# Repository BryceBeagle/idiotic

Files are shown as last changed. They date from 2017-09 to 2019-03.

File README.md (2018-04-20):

The purpose of this project was to create a modular Internet of Things (IoT) system to create an interface between DIY
devices and consumer grade products. The end product is focused on the automation of household tasks and behaviors for
these devices, with functionality resembling a combination of IFTTT (If This Then That; used for integration between
different web services) and Tasker (used for automating system actions on a cellphone). Users have the ability to
integrate devices and services from off-the-shelf products and services, as well as third party or homebrewed solutions.

This project provides a design architecture as well as an implementation thereof. The architecture describes a system
that addresses all of the design requirements, while the implementation makes it happen. The implementation provides the
software required to run the system, as well as a set of physical modules that are able to work with it. The modules
include parts lists, PCB schematics, board designs, and embedded software ‒ everything required to create and deploy one
from scratch.

Users are able to configure their system to create collections of tasks, called routines, that are triggered by internal
or external state changes, such as the time transitioning to a predesignated time of the day, or a door being opened.
These routines contain events, or sequences of actions to perform, where each action is an atomic operation for a device
to execute. A routine can contain one or more events, and each event can contain one or more actions to perform. For
example, if a user wants their Philips Hue internet-connected light bulbs to turn on automatically when they open a
specific door, they can create a routine that is run when a predesignated door sensor is activated. Devices send status
updates to a server which listens to the changing values and notifies routines that are subscribed to pieces of data.

The system has a server that handles connections and routes incoming data to device driver instances using a data
control library, henceforth referred to as the controller. The controller manages routines and events in the system as
well as the data structure that holds all of the device instances. Devices, both physical (e.g., a Temperature Sensor)
and cloud-based (e.g., a Google Home), are configured for use by the controller with driver files that express the
capabilities of the hardware or software that they represent. For example, a driver for the Philips Hue smart light
bulbs would express the ability to set and retrieve attributes such as brightness, hue, saturation and on/off state, as
well as behaviors such as dimming and pulsing.

Routines, events, and devices are stored in a configuration, allowing the system to start up preconfigured and ready for
use. Events referenced in routines must have corresponding configuration entries describing them, and devices mentioned
in events must also have drivers that the controller can access and utilize. Storing configurations in non-volatile,
text-based formats allows them to be version controlled, shared, and edited with relative ease.

The software provided with this project, called Idiotic, is an extendable implementation of the system described above.
It is written in Python 3, with the server implemented with the Flask web framework library. Routines, events, and
devices are loaded from JSON configuration files. There are also a small number of PCB devices, designed using Eagle,
that function with the system as a demonstration of functionality.

Developers that wish to integrate their own devices into Idiotic can make use of the server’s client platform agnostic
websocket-based API to integrate their device within the system, using the simple, documented protocol. Creating a
single driver file in a designated directory is all that is required to allow the controller to handle data from, and
make commands to, a new device type. All integrated devices are treated as a first-class citizens within the system.

Furthermore, if the new device is built on an ESP8266 microcontroller platform, there is a provided library that allows
for expedited embedded development and integration within the system. A developer simply needs to extend a template file
to map which functions are correlated with which pieces of data and behaviors. If the new device is unable to utilize
this library, it simply needs to connect to the server over a Websocket and follow a simple communication protocol.

Modules currently in the system:
* Door Open/Close Sensor (already developed but revising is necessary)
* IR blaster/receiver **(hardware only)** - Send IR signals to TV (with ability to record and reproduce remote signals)
* HVAC Thermostat
* Temperature sensor
* Hue Light support
		
Core features of the software  include:
* Ability to utilize and integrate all created PCB modules
* Ability to interface modules together to create useful routines and actions
* Ability to add DIY modules with an easy to use interface

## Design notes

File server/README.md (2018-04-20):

# Introduction

`idiotic_server.py` is the entry point of the software portion of this project. It operates as the glue that holds the
Model and Controller together. In the future the server will serve the View of the system. The server operates as the
communication layer between the devices and the controller. Modules send HTTP PUT requests to the server to notify it of
any changes in the information they measure. Modules also occasionally send the values to the server even if they have
not changes as a way of informing the server that the information is still correct.

It is run without arguments using Python 3 and has the following dependencies:

Required:
* `flask` -- Runs the webserver

Optional:
* `phue` -- Required to use Phillips Hue lights and bridges*

<sub><sup>\* currently required because of some hardcoding -- to be optional in future.<sup><sub>

The devices and the server communicate with each other using websockets. The data is sent on the socket in the form of
string encoded JSON structures. Each JSON structure is an object with one or more of two currently supported keys:
hello and update. The value associated with the key is an array of tasks of that type for the recipient to perform.
Depending on the intended recipient of the message, these instructions are slightly different.

An IdioticDevice sends a hello message attempting to establish connection to the server, usually during its
initialization sequence. If the message is a hello message, the json structure must contain a class type in the
"class" key to be associated with the uuid.

Below are example JSON objects, for each message type:

hello structure:
```javascript
{
  "hello": null,
  "uuid": "13:8C:14:87:B7:AD",
  "class": "DoorSensor"
}
```
update structure:
```javascript
{
  "uuid": "13:8C:14:87:B7:AD",
  "update": {
    "door_state": 1,
    "some_value": "some string"
  }
}
```
get structure:
```
[unimplemented]
```

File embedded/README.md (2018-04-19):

# Introduction
Each module is built on top of the ESP8266 embedded platform. All devices connect to a local network and communicate with the `idiotic-server`. Json is tranferred using HTTP Requests and can be used to instruct a device to perform and action or respond with information. 

To aid in simplicity, familiarity and library support, the [Arduino core](https://github.com/esp8266/Arduino "Arduino core") is used. This allows easy programming in C++ with access to a number of convient libraries such as Serial, Wire (TWI/I2C), and Servo.

The [ESP8266WiFi library](https://github.com/esp8266/Arduino/tree/master/libraries/ESP8266WiFi "ESP8266WiFi library") is used to connect the module to a local WiFi network. It's very easy to setup, requiring a single method call with the SSID and password.

Json data structures are  [ArduinoJson library](https://github.com/bblanchon/ArduinoJson "ArduinoJson library"). It provides an easy method of constructing Json data structures that can be turned into strings and sent. 

# Creating your own
It is recommended to use PlatformIO toolchain for development and deployment of software to the ESP8266.

1. If you are developing a new device, create a new directory under `$idiotic/embedded/src` with the name of your device
2. Create a new `.cpp` source file in that directory and open it for editing
3. Import `idiotic_module.hpp` to acquire the base IdioticModule class and its functionality
4. Create an instance of `IdioticModule`, passing the device type as a string.

    Note: This string must exactly match the class name of the corresponding device driver
5. In the setup() function:
    1. Connect the module to WiFi using `IdioticModule::connectWiFi()`
    2. Begin the connection to the Idiotic server using `IdioticModule::beginSocket()`
    3. Populate the `Idiotic::funcs` map with attribute set and get functions using `IdioticModule::function_map`
    structs. The key for each item in the map is the attribute name.

        Note:
        * Each key must have an exact match in the corresponding device driver as either an attribute or a behavior
        * The `.get` function supports lambda expressions, but for an unknown technical reason, I was unable to get this
        working for the `.set` function. As a result, only function pointers are accepted. If a class method is required,
        use `std::bind` for now.
    4. If serial debug output is desired, use `Serial.setDebugOutput(true)`
6. In the loop() function:
    1. Run the dataloop using `IdioticModule::dataLoop()`
    2. Delay the thread to for an amount of time to meet a desired period using `delay()`

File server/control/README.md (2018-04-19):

This directory is for all things controller. A summary of the purposes of each file/directory is provided below:

* `device_drivers/` - Directory where device-drivers should be placed. These files outline the abilities of each device
in the system
* `idiotic_conditional.py` - Contains the `IdioticConditional` class, used by IdioticRoutines and IdioticEvents for
requirements testing before executing
* `idiotic_controller.py` - The meat of the directory. Manages device driver instances and IdioticRoutines
* `idiotic_device.py` - Has base `IdioticDevice` class for device drivers to inherit from, as well as `Attributes` and
`Behavior` decorators
* `idiotic_routine.py` - Contains the `IdioticRoutine` class, which manage the flow of functionality in the system
* `idiotic_trigger.py` - Contains the `IdioticTrigger` class, used by IdioticRoutines to subscribe to device attributes

See the readme in `device_drivers/` for how to create a new device driver to be added to the system

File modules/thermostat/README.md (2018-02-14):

# Introduction
Module that acts as a replacement/attachment to a household thermostat

# Background
A standard thermostat attaches to a number of wires that lead to the HVAC system. These wires typically run at ~24 VAC and are usually color coded. The ones we need to worry about are:

|  Marking | Wire Color  | Purpose  |
| :--- | :--- | :--- |
| R  | Red  | 24 VAC  |
| G  | Green  | Fan Relay  |
| W  | White  | Heat Relay  |
| Y  | Yellow  | AC Relay |

If your current thermostat has a heat anticipator -- [TODO]

# Functionality

# Parts List

# Appendix

**Choosing a current limiting resistor between the ESP and relays**

See [here](https://electronics.stackexchange.com/a/16219/163386 "here") for a great description on how to read the datasheet for a Solid State Relay.

| | |
| - | - |
| ESP Supply Voltage  | 3.3 V  |
| SSR LED Voltage Drop  | 1.2 V  |
| Desired SSR Current | 1 mA |

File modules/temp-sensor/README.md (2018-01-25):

**Description**

Module that measures and reports temperature.

The MCP9808 sensor is functional from -40°C ~ 125°C with an accuracy of ±0.5°C. The ESP8266 communicates with the sensor
using I2C (TWI). Temperature is measured every 30 seconds and a 5 minute rolling average is reported to the server every
30 seconds.

Temperature is reported in °C the following JSON format:
```json
{"temp" : "20.5"}
```

**Parts List**

| Purpose | Component(s) | Purchase Link |
|---|---|---|
| Microcontroller | ESP8266-07 or ESP8266-12E/F/S | [Link](https://www.adafruit.com/product/2491)|
| Temp Sensor | MCP9808 in 8-MPOS package | [Link](https://www.digikey.com/short/q8143w) |
| SMD Female MicroUSB | 609-4613-1-ND | [Link](https://www.digikey.com/short/q81438) |
| 3.3 V Voltage Reg | AZ1117E in SOT-223 package | [Link](https://www.digikey.com/short/q81489) |
| VReg Caps | 2 × 1 μF capacitors in 0805 package | |

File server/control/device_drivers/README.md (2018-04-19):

# Creating a new IdioticDevice

Creating a new IdioticDevice is simple. First, create a new python file in the `control/device_drivers` directory.
Use the following snippet as a template/example for the file:
```python
from control.idiotic_device import IdioticDevice
from control.idiotic_device import Attribute, Behavior

class MyDeviceName(IdioticDevice):

    def __init__(self):
        self._my_attribite = None

    @Attribute
    def my_attribute():
        """Get my_attribute from device or from controller if cached

        Implicit my_attribute.getter
        """
        # In this case, the value is retrieved from cache
        return self._my_attribute

    @my_attribute.setter
    def my_attribute(value):
        """Instruct device to set my_attribute to value"""
        self.ws.get().send(f'{{"set" : {{"{active_device}"}}}}')

    @my_attribute.updater
    def my_attribute(value):
        """Update value of my_attribute in controller's cache"""
        self._my_attribute = value

    @Behavior
    def thing_to_do(param1, param2):
        """Have device do some thing"""
        self.ws.get().send(f'{{"do" : "thing_to_do"}}')

```

IdioticDevices consist of two main components: Attributes and Behaviors. Attributes represent singular values and states,
while Actions are meant to be used to perform something a little more in depth. For example, the brightness of a Hue
Light would be an attribute, and a command used to make the bulb strobe between 3 colors would be an Action.

## Attributes

Attributes represent singular values and states. For example, the brightness of a Hue Light would be an attribute, and
would have a getter and a setter method. Because the HueLights do not ping the server with status information, the
HueLight Attributes would not have updater methods. On the other hand, a temperature sensor whose sole purpose is to
report status would have updater and getter functions for its temp attribute.

Attributes are defined above a function use decorators. The plain @Attribute decorator must be used first and designates
the following function as the getter function for the Attribute. To define a setter or updater function use
`getter_func_name.setter` or `getter_func_name.updater`, where getter_func_name is the name of the function defined as
the getter function.

## Behaviors

Behaviors are abilities that a device can perform, that are slightly more complicated that the setting of a single value
that an attribute setter function provides. An example of a behavior could be a HueLight having a transition ability to
slowly change between two different colors, which would be arguments fort the behavior function. Behaviors are not as
complicated internally as attributes and only have a single method. However, the @Behavior decorator must be used to
tell Idiotic to enumerate the Behavior and allow Routines to call it.

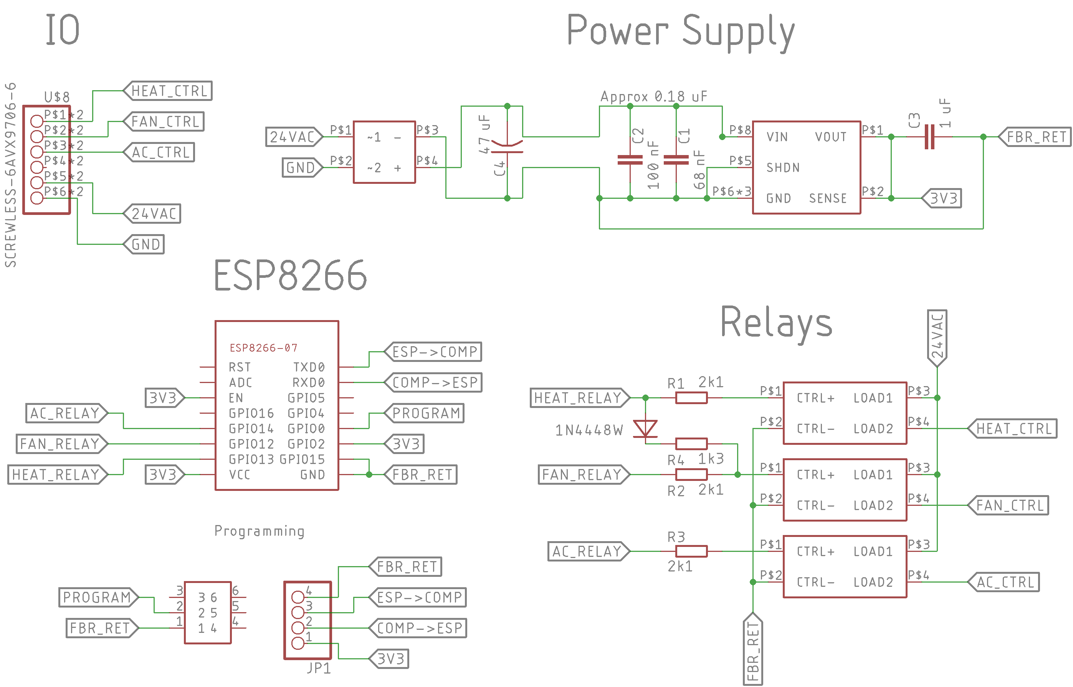
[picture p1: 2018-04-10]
eagle/modules/thermostat/schematic.png

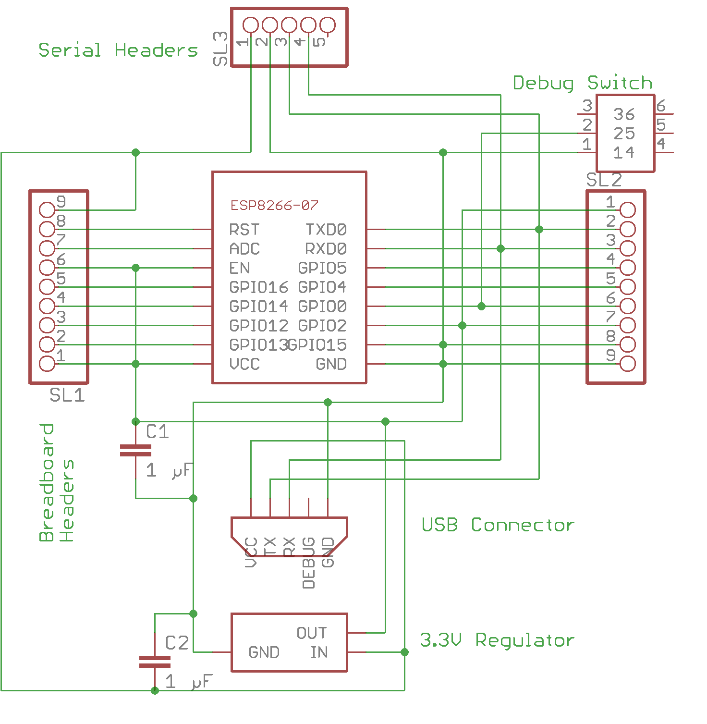
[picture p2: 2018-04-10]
eagle/modules/breakout-board/schematic.png

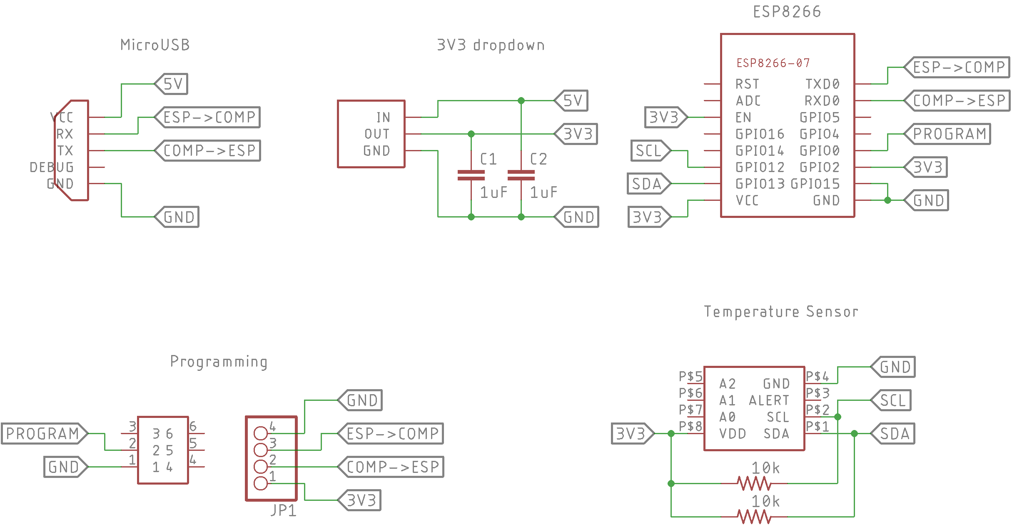
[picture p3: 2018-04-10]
eagle/modules/temp-sensor/schematic.png

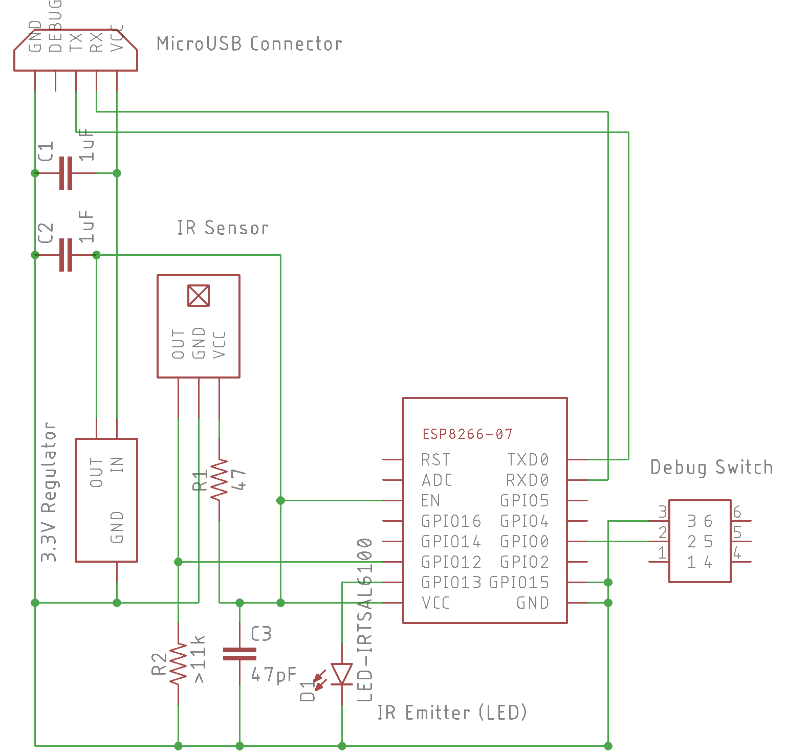
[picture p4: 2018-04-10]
eagle/modules/ir/schematic.png

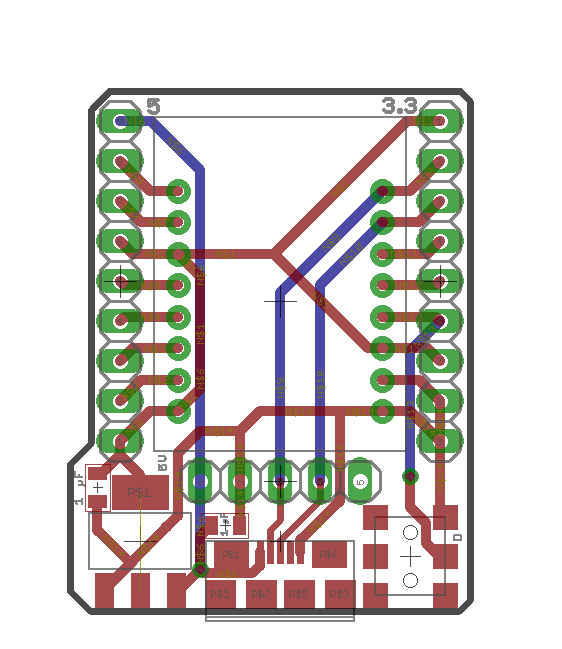
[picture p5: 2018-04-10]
eagle/modules/breakout-board/board.png

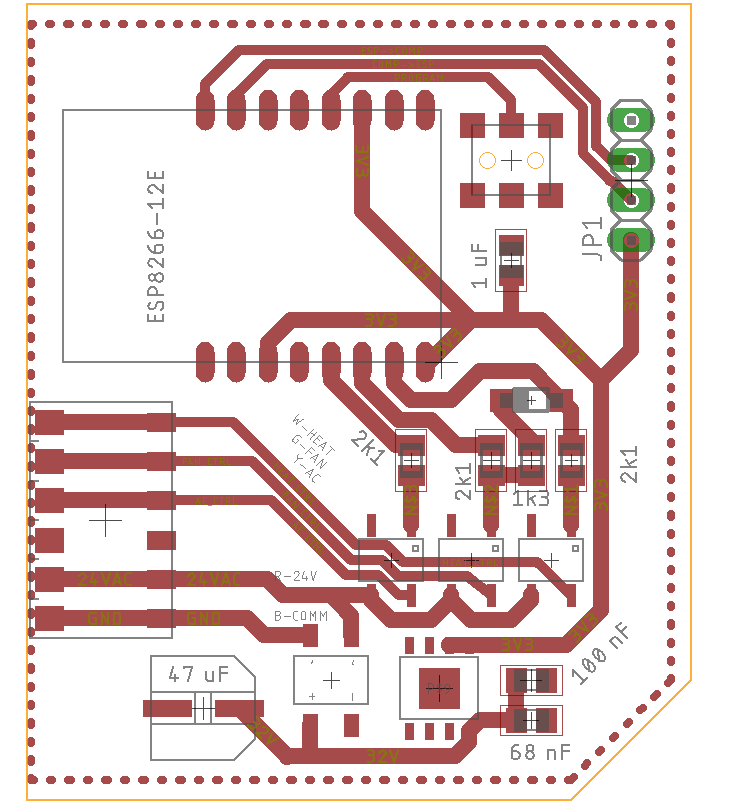
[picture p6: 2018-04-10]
eagle/modules/thermostat/board.png

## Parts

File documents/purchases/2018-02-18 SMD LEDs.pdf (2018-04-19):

701 Brooks Ave South,

### PO Box 677 Thief River Falls, MN 56701-0677

### www.digikey.com Orders 1-800-344-4539 Fax 218-681-3380

## Invoice # 61406250

# Completed Salesorder U.S. $

Claims for pricing errors, shortages, and defective product must be reported within 30 days of invoice date.

## Contact Customer Service at 1-800-858-3616

All transactions with Digi-Key Electronics, including its subsidiaries and/or affiliates, are
subject to Digi-Key's Terms of Use and Conditions of Order, available at www.digikey.com.
DUNS No: 05 760 2120 FEI No: 41-1234968 Any applicable sales tax not collected on this invoice is the responsibility of the customer

### Page: 1 of 2

### Bill To:

### BRYCE BEAGLE 6215 E BEVERLY LN SCOTTSDALE AZ 85254-0000

### Ship To:

### BRYCE BEAGLE BEAGLE ENTERPRISES 6355 S TERRIPIN MESA AZ 85212-0000

### Buyer:

### BRYCE BEAGLE BEAGLE ENTERPRISES 6355 S TERRIPIN MESA AZ 85212-0000

### Ship From:

### DIGI-KEY 701 BROOKS AVE. SOUTH P.O. BOX 677 THIEF RIVER FALLS MN 56701-0677

Salesorder / Packlist: | 53670626 / PL1
Customer: | 9708463
Payment Terms: Shipping Method: Tracking #: | VISA / 2148
| FC
| 9200190106460328886854
Order Source: | INTERNET
Order Date: Invoice Date: Ship Date: | 13-Feb-2018
| 13-Feb-2018
| 13-Feb-2018
Document Date: | 13-Feb-2018/AUTO

### Line

Item | Ordered | Cancelled | Shipped | Item Number/ Description | Unit Price
U.S. $

### Amount

U.S. $

1 | 25 | 0 | 25 | PART: LTST-C191KFKT
CUST: ORANGE SMD LED
| | | | DESC: LED ORANGE CLEAR 0603 SMD LEAD FREE ROHS COMP REACH UNKNOWN
COO : CHINA | ECCN: EAR99 | HTSUS: 8541.40.2000
0.14480 | 3.62 T

Mercury: Cert on File. For more information contact RoHS@DigiKey.com

2 | 25 | 0 | 25 | PART: LTST-C191KSKT CUST: YELLOW SMD LED

DESC: LED YELLOW CLEAR 0603 SMD LEAD FREE ROHS COMP REACH UNKNOWN
COO : CHINA | ECCN: EAR99 | HTSUS: 8541.40.2000
0.16560 | 4.14 T

Mercury: Cert on File. For more information contact RoHS@DigiKey.com

3 | 25 | 0 | 25 | PART: LTST-C191KGKT CUST: GREED SMD LED

DESC: LED GREEN CLEAR 0603 SMD LEAD FREE ROHS COMP REACH UNKNOWN
COO : CHINA | ECCN: EAR99 | HTSUS: 8541.40.2000
0.15560 | 3.89 T

Mercury: Cert on File. For more information contact RoHS@DigiKey.com

4 | 25 | 0 | 25 | PART: LTST-C191KRKT CUST: RED SMD LED

DESC: LED RED CLEAR 0603 SMD LEAD FREE ROHS COMP REACH UNKNOWN
COO : CHINA | ECCN: EAR99 | HTSUS: 8541.40.2000
0.15560 | 3.89 T

Mercury: Cert on File. For more information contact RoHS@DigiKey.com

Total Invoiced
Shipping charges applied
** Charges subtotal **
Sales tax
Total charged to credit card

15.54 -
3.75 -
19.29 -
1.14 -
20.43 -
U.S. $.
T indicates taxable amounts -* These items are controlled by the U.S. Government and authorized for export only to the country of ultimate destination for use by the ultimate consignee or end-user(s) herein identified. They may not be resold, transferred, or otherwise disposed of, to any other country or to any person other than the authorized ultimate consignee or end-user(s), either in their original form or after being incorporated into other items, without first obtaining approval from the U.S. Government or as otherwise authorized by U.S. law and regulations.

Box(es):

701 Brooks Ave South,

### PO Box 677 Thief River Falls, MN 56701-0677

### www.digikey.com Orders 1-800-344-4539 Fax 218-681-3380

## Invoice # 61406250

# Completed Salesorder U.S. $

Claims for pricing errors, shortages, and defective product must be reported within 30 days of invoice date.

## Contact Customer Service at 1-800-858-3616

All transactions with Digi-Key Electronics, including its subsidiaries and/or affiliates, are
subject to Digi-Key's Terms of Use and Conditions of Order, available at www.digikey.com.
DUNS No: 05 760 2120 FEI No: 41-1234968 Any applicable sales tax not collected on this invoice is the responsibility of the customer

### Page: 2 of 2

1 | FC | 9200190106460328886854 | 0.23 kg / 8 oz
25 | LTST-C191KFKT
25 | LTST-C191KSKT
| | | Continued...
25 | LTST-C191KGKT
25 | LTST-C191KRKT

General - WEB ORDER ID: 178395228

CERTIFICATE OF COMPLIANCE:
The Digi-Key components included in the above shipment are genuine components and were provided by the applicable manufacturer to Digi-Key. Test reports (chemical, physical, electrical, etc., together with results of any tests performed by the manufacturer) are on file (either here or in the plant of the manufacturer) and will be made available upon request. These components have been handled in accordance with the requirements of applicable quality standards. This certification is valid only to the original customer and is not transferable. Contact Customer Service at 800-858-3616 if you have any questions.

### Kim Gilbert, Director, Customer Service

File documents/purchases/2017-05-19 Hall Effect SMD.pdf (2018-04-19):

For Office
Use Only
Received | Billing | Pack List No.

## Sold To: Bill To:

Claims for pricing errors, shortages, and defective product must be reported within 30 days of invoice date.

Printing Date

### Back Orders

### Sales Order

### Account

### Customer Purchase Order

Invoice Date | Page
Entered By / Date | Shipped Via

### Terms

Idx | Box | Ordered | Cancelled | Shipped | Item Number/Description | Back Order
Unit Price | Amount
Currency Type: | MSC #

1

1 | 1 | 10 | 0 | 10 AH9246-W-7DICT-ND | .57000 | 5.70 T
| | | | MAGNETIC SWITCH OMNIPOLAR SC59
| | | | CUST REF #: SMD HALL EFFECT
HTSUS: 8542.39.0001 | ECCN: EAR99
LEAD: LEAD FREE | ROHS: ROHS COMP | REACH: REACH | UNAFFECTED | JAN-2017

### Mercury: Cert on File. For more information contact RoHS@DigiKey.com

| | | | COUNTRY/ORIGIN: CHINA
| | | | CAGE: 6M0U4
| | | | PACKAGE TRACKING #: 9200190106460324890602
BOX | 1 SHIPPED FC | WEIGHT | 0 LBS 5 OZS (0.14 KG)
| | | | BOX ID 9200190106460324890602
| | | | TOTAL INVOICED | | 5.70
| | | | SHIPPING CHARGES APPLIED | | 2.85
| | | | ** CHARGES SUBTOTAL ** | | 8.55
| | | | SALES TAX | | .42
| | | | (T INDICATES TAXABLE AMOUNTS)
| | | | TOTAL CHARGED TO CREDIT CARD | | 8.97
| | | | | | U.S. $$

### YOUR CREDIT CARD HAS BEEN CHARGED THE ABOVE INDICATED AMOUNT

| | | | THE ORDER IS COMPLETE
| | | | Ship To: BRYCE BEAGLE
| | | | BEAGLE ENTERPRISES
| | | | 6355 S TERRIPIN
| | | | MESA AZ 85212-0000
| | | | Ship From: DIGI-KEY
| | | | 701 BROOKS AVE. SOUTH
| | | | P.O. BOX 677
| | | | THIEF RIVER FALLS MN 56701-0677
| | | | General - WEB ORDER ID: 168880240

## www.digikey.com Orders 1-800-344-4539 Fax 218-681-3380

# Invoice # 57865523

U.S. $

### 701 Brooks Ave. South, Thief River Falls, MN 56701-0677 USA

### CUSTOMER 9708463 BRYCE BEAGLE BEAGLE ENTERPRISES 6355 S TERRIPIN MESA AZ 85212-0000

Visa | 19-MAY-2017

50520347

Accepts to 14-MAY-2018 | 2897396

## BRYCE BEAGLE 6215 E BEVERLY LN SCOTTSDALE AZ 85254-0000

### Ship Date

AUTO/19-MAY-2017 | FC | 19-MAY-2017

# Easy to Remember: 1-800-DIGI-KEY

VAT/Tax ID
INTERNET | BILL SHIP | 1 | 19-MAY-2017 | U.S. $ | 0
US $ | US $

# Contact Customer Service at 1-800-858-3616

## All transactions with Digi-Key, including its subsidiaries and/or affiliates, are subject to Digi-Key's Terms of Use and

Conditions of Order, available at www.digikey.com.

DUNS No: 05 760 2120 FEI No: 41-1234968 Any applicable sales tax not collected on this invoice is the responsibility of the customer.

## Sold To:

Claims for pricing errors, shortages, and defective product must be reported within 30 days of invoice date.

Idx | Box | Ordered | Cancelled | Shipped | Item Number/Description | Back Order
Unit Price | Amount

Terms

Customer Purchase Order

Invoice Date | Page

Shipped Via

2

## www.digikey.com Orders 1-800-344-4539 Fax 218-681-3380

# Invoice # 57865523

U.S. $

### 701 Brooks Ave. South, Thief River Falls, MN 56701-0677 USA

### CUSTOMER 9708463 BRYCE BEAGLE BEAGLE ENTERPRISES 6355 S TERRIPIN MESA AZ 85212-0000

Visa | 19-MAY-2017

FC

## Easy to Remember: 1-800-DIGI-KEY

US $ | US $

# Contact Customer Service at 1-800-858-3616

## All transactions with Digi-Key, including its subsidiaries and/or affiliates, are subject to Digi-Key's Terms of Use and

Conditions of Order, available at www.digikey.com.

DUNS No: 05 760 2120 FEI No: 41-1234968 Any applicable sales tax not collected on this invoice is the responsibility of the customer. These items are controlled by the U.S. Government and authorized for export only to the country of ultimate destination for use by the ultimate consignee or end-user(s) herein identified. They may not be resold, transferred, or otherwise disposed of, to any other country or to any person other than the authorized ultimate consignee or end-user(s), either in their original form or after being incorporated into other items, without first obtaining approval from the U.S. Government or as otherwise authorized by U.S. law and regulations.

CERTIFICATE OF COMPLIANCE: | The Digi-Key components included in the above shipment are genuine components and were provided by the applicable manufacturer to Digi-Key. Test reports (chemical, physical, electrical, etc., together with results of any tests performed by the manufacturer) are on file (either here or in the plant of the manufacturer) and will be made available upon request. These components have been handled in accordance with the requirements of applicable quality standards. This certification is valid only to the original customer and is not transferable. Contact Customer Service at 800-858-3616 if you have any questions.
| Kim Gilbert, Director, Customer Service

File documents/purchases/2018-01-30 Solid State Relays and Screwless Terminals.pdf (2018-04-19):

For Office
Use Only
Received | Billing | Pack List No.

## Sold To: Bill To:

Claims for pricing errors, shortages, and defective product must be reported within 30 days of invoice date.

Printing Date

### Back Orders

### Sales Order

### Account

### Customer Purchase Order

Invoice Date | Page
Entered By / Date | Shipped Via

### Terms

Idx | Box | Ordered | Cancelled | Shipped | Item Number/Description | Back Order
Unit Price | Amount
Currency Type: | MSC #

1

1 | 1 | 5 | 0 | 5 478-6171-1-ND | .90000 | 4.50 T
| | | | CONN TERM BLOCK 4 POS WTB
| | | | CUST REF #: SMD 4 PIN TERMINALS
HTSUS: 8536.69.4040 | ECCN: EAR99
LEAD: LEAD FREE | ROHS: ROHS COMP | REACH: REACH | UNAFFECTED | JUL-2017

### Mercury: Cert on File. For more information contact RoHS@DigiKey.com

| | | | COUNTRY/ORIGIN: CHINA
| | | | CAGE: 6KUV2
2 | 1 | 5 | 0 | 5 CLA233DKR-ND | 2.56000 | 12.80 T
| | | | RELAY OPTOMOS SP-NO 100MA 4-SOP
| | | | CUST REF #: RELAYS
HTSUS: 8541.40.9500 | ECCN: EAR99
LEAD: LEAD FREE | ROHS: ROHS COMP | REACH: REACH | UNAFFECTED | JUL-2017

### Mercury: Cert on File. For more information contact RoHS@DigiKey.com

| | | | COUNTRY/ORIGIN: PHILIPPINES
| | | | CAGE: 1E9M5
| | | | PACKAGE TRACKING #: 9200190106460328659298
BOX | 1 SHIPPED FC | WEIGHT | 0 LBS 10 OZS (0.28 KG)
| | | | BOX ID 9200190106460328659298
| | | | TOTAL INVOICED | | 17.30
| | | | SHIPPING CHARGES APPLIED | | 4.45
| | | | ** CHARGES SUBTOTAL ** | | 21.75
| | | | SALES TAX | | 1.27
| | | | (T INDICATES TAXABLE AMOUNTS)
| | | | TOTAL CHARGED TO CREDIT CARD | | 23.02
| | | | | | U.S. $$

### YOUR CREDIT CARD HAS BEEN CHARGED THE ABOVE INDICATED AMOUNT

| | | | THE ORDER IS COMPLETE
| | | | Ship To: BRYCE BEAGLE
| | | | BEAGLE ENTERPRISES
| | | | 6355 S TERRIPIN
| | | | MESA AZ 85212-0000

## www.digikey.com Orders 1-800-344-4539 Fax 218-681-3380

# Invoice # 61191257

U.S. $

### 701 Brooks Ave. South, Thief River Falls, MN 56701-0677 USA

### CUSTOMER 9708463 BRYCE BEAGLE BEAGLE ENTERPRISES 6355 S TERRIPIN MESA AZ 85212-0000

Visa | 30-JAN-2018

53480200

Accepts to 25-JAN-2019 | 2897396

## BRYCE BEAGLE 6215 E BEVERLY LN SCOTTSDALE AZ 85254-0000

### Ship Date

AUTO/30-JAN-2018 | FC | 30-JAN-2018

# Easy to Remember: 1-800-DIGI-KEY

VAT/Tax ID
INTERNET | BILL SHIP | 1 | 30-JAN-2018 | U.S. $ | 0
US $ | US $

# Contact Customer Service at 1-800-858-3616

## All transactions with Digi-Key, including its subsidiaries and/or affiliates, are subject to Digi-Key's Terms of Use and

Conditions of Order, available at www.digikey.com.

DUNS No: 05 760 2120 FEI No: 41-1234968 Any applicable sales tax not collected on this invoice is the responsibility of the customer.

## Sold To:

Claims for pricing errors, shortages, and defective product must be reported within 30 days of invoice date.

Idx | Box | Ordered | Cancelled | Shipped | Item Number/Description | Back Order
Unit Price | Amount

Terms

Customer Purchase Order

Invoice Date | Page

Shipped Via

2

### Ship From: DIGI-KEY 701 BROOKS AVE. SOUTH P.O. BOX 677 THIEF RIVER FALLS MN 56701-0677

### General - WEB ORDER ID: 177748739

## www.digikey.com Orders 1-800-344-4539 Fax 218-681-3380

# Invoice # 61191257

U.S. $

### 701 Brooks Ave. South, Thief River Falls, MN 56701-0677 USA

### CUSTOMER 9708463 BRYCE BEAGLE BEAGLE ENTERPRISES 6355 S TERRIPIN MESA AZ 85212-0000

Visa | 30-JAN-2018

FC

## Easy to Remember: 1-800-DIGI-KEY

US $ | US $

# Contact Customer Service at 1-800-858-3616

## All transactions with Digi-Key, including its subsidiaries and/or affiliates, are subject to Digi-Key's Terms of Use and

Conditions of Order, available at www.digikey.com.

DUNS No: 05 760 2120 FEI No: 41-1234968 Any applicable sales tax not collected on this invoice is the responsibility of the customer. These items are controlled by the U.S. Government and authorized for export only to the country of ultimate destination for use by the ultimate consignee or end-user(s) herein identified. They may not be resold, transferred, or otherwise disposed of, to any other country or to any person other than the authorized ultimate consignee or end-user(s), either in their original form or after being incorporated into other items, without first obtaining approval from the U.S. Government or as otherwise authorized by U.S. law and regulations.

CERTIFICATE OF COMPLIANCE: | The Digi-Key components included in the above shipment are genuine components and were provided by the applicable manufacturer to Digi-Key. Test reports (chemical, physical, electrical, etc., together with results of any tests performed by the manufacturer) are on file (either here or in the plant of the manufacturer) and will be made available upon request. These components have been handled in accordance with the requirements of applicable quality standards. This certification is valid only to the original customer and is not transferable. Contact Customer Service at 800-858-3616 if you have any questions.
| Kim Gilbert, Director, Customer Service

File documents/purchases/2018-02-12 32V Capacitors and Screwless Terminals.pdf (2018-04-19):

701 Brooks Ave South,

### PO Box 677 Thief River Falls, MN 56701-0677

### www.digikey.com Orders 1-800-344-4539 Fax 218-681-3380

## Invoice # 61525620

# Completed Salesorder U.S. $

Claims for pricing errors, shortages, and defective product must be reported within 30 days of invoice date.

## Contact Customer Service at 1-800-858-3616

All transactions with Digi-Key Electronics, including its subsidiaries and/or affiliates, are
subject to Digi-Key's Terms of Use and Conditions of Order, available at www.digikey.com.
DUNS No: 05 760 2120 FEI No: 41-1234968 Any applicable sales tax not collected on this invoice is the responsibility of the customer

### Page: 1 of 2

### Bill To:

### BRYCE BEAGLE 6215 E BEVERLY LN SCOTTSDALE AZ 85254-0000

### Ship To:

### BRYCE BEAGLE BEAGLE ENTERPRISES 6355 S TERRIPIN MESA AZ 85212-0000

### Buyer:

### BRYCE BEAGLE BEAGLE ENTERPRISES 6355 S TERRIPIN MESA AZ 85212-0000

### Ship From:

### DIGI-KEY 701 BROOKS AVE. SOUTH P.O. BOX 677 THIEF RIVER FALLS MN 56701-0677

Salesorder / Packlist: | 53775142 / PL1
Customer: | 9708463
Payment Terms: Shipping Method: Tracking #: | VISA / 2148
| FC
| 9200190106460329025573
Order Source: | INTERNET
Order Date: Invoice Date: Ship Date: | 21-Feb-2018
| 21-Feb-2018
| 21-Feb-2018
Document Date: | 21-Feb-2018/AUTO

### Line

Item | Ordered | Cancelled | Shipped | Item Number/ Description | Unit Price
U.S. $

### Amount

U.S. $

1 | 5 | 0 | 5 | PART: 478-6172-1-ND
CUST: SCREWLESS 6 TERMINALS
| | | | DESC: CONN TERM BLOCK 6 POS WTB LEAD FREE ROHS COMP REACH UNAFFECTED Jul-2017
COO : CHINA | ECCN: EAR99 | HTSUS: 8536.69.4040
1.17000 | 5.85 T

Mercury: Cert on File. For more information contact RoHS@DigiKey.com

2 | 5 | 0 | 5 | PART: 493-2202-1-ND CUST: 32 V FBR RIPPLE CAP

DESC: CAP ALUM 47UF 20% 35V SMD
LEAD FREE ROHS COMP REACH UNAFFECTED Jan-2017
COO : JAPAN | ECCN: EAR99 | HTSUS: 8532.22.0020
0.36000 | 1.80 T

Total Invoiced
Shipping charges applied
** Charges subtotal **
Sales tax
Total charged to credit card

7.65 -
3.75 -
11.40 -
0.56 -
11.96 -
U.S. $.
T indicates taxable amounts -* These items are controlled by the U.S. Government and authorized for export only to the country of ultimate destination for use by the ultimate consignee or end-user(s) herein identified. They may not be resold, transferred, or otherwise disposed of, to any other country or to any person other than the authorized ultimate consignee or end-user(s), either in their original form or after being incorporated into other items, without first obtaining approval from the U.S. Government or as otherwise authorized by U.S. law and regulations.

Box(es):
1 | FC | 9200190106460329025573 | 0.17 kg / 6 oz
5 | 478-6172-1-ND
| | | Continued...
5 | 493-2202-1-ND

General - WEB ORDER ID: 178438095

701 Brooks Ave South,

### PO Box 677 Thief River Falls, MN 56701-0677

### www.digikey.com Orders 1-800-344-4539 Fax 218-681-3380

## Invoice # 61525620

# Completed Salesorder U.S. $

Claims for pricing errors, shortages, and defective product must be reported within 30 days of invoice date.

## Contact Customer Service at 1-800-858-3616

All transactions with Digi-Key Electronics, including its subsidiaries and/or affiliates, are
subject to Digi-Key's Terms of Use and Conditions of Order, available at www.digikey.com.
DUNS No: 05 760 2120 FEI No: 41-1234968 Any applicable sales tax not collected on this invoice is the responsibility of the customer

### Page: 2 of 2

CERTIFICATE OF COMPLIANCE:
The Digi-Key components included in the above shipment are genuine components and were provided by the applicable manufacturer to Digi-Key. Test reports (chemical, physical, electrical, etc., together with results of any tests performed by the manufacturer) are on file (either here or in the plant of the manufacturer) and will be made available upon request. These components have been handled in accordance with the requirements of applicable quality standards. This certification is valid only to the original customer and is not transferable. Contact Customer Service at 800-858-3616 if you have any questions.

### Kim Gilbert, Director, Customer Service

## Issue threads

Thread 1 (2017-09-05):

Breakout board header drill holes are too small

BryceBeagle, 2017-09-05:

Closed 2017-09-21.

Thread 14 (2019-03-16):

Server should print a warning/error when it receives an invalid json packet

BryceBeagle, 2019-03-16:

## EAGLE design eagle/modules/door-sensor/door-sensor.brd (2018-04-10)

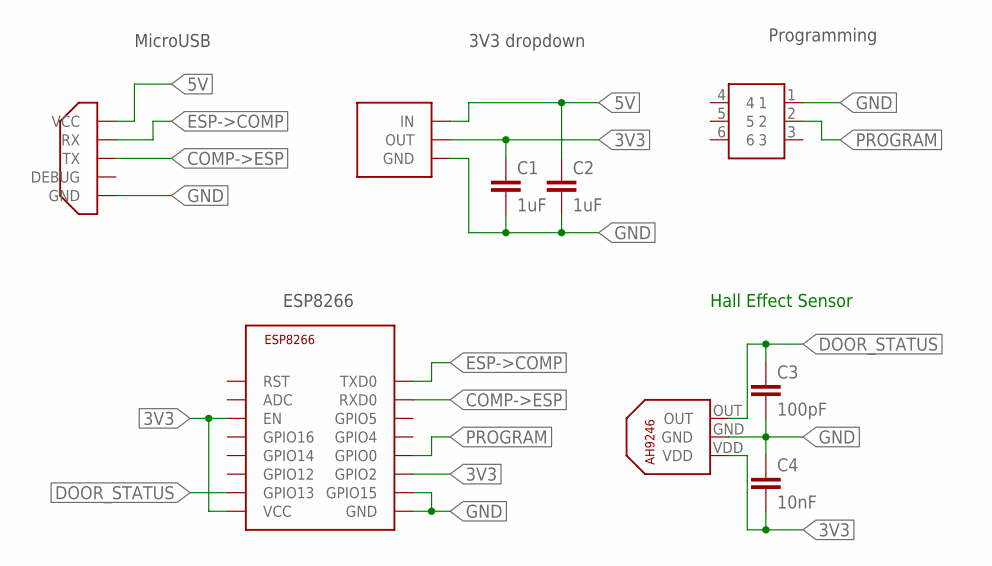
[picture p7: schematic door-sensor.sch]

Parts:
C1, C2: 1uF; C0805
C3: 100pF; C0805
C4: 10nF; C0805
U$2: MICROUSB609-4613-1-ND; MICROUSB
U$4: AZ1117E; SOT-223
U$6: ESP8266-12E-SMD
U$7: AYZ0202AGRL
U$8: AH9246SC59; SC59

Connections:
3V3: C1.1, C4.2, U$4.P$1 (OUT), U$4.P$2 (OUT), U$6.EN, U$6.GPIO2, U$6.VCC, U$8.VDD
5V: C2.1, U$2.VCC, U$4.P$4 (IN)
COMP->ESP: U$2.TX, U$6.RXD0
DOOR_STATUS: C3.1, U$6.GPIO13, U$8.OUT
ESP->COMP: U$2.RX, U$6.TXD0
GND: C1.2, C2.2, C3.2, C4.1, U$2.GND, U$4.P$3 (GND), U$6.GND, U$6.GPIO15, U$7.1, U$8.GND
PROGRAM: U$6.GPIO0, U$7.2

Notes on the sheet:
MicroUSB
3V3 dropdown
ESP8266
Programming
Hall Effect Sensor

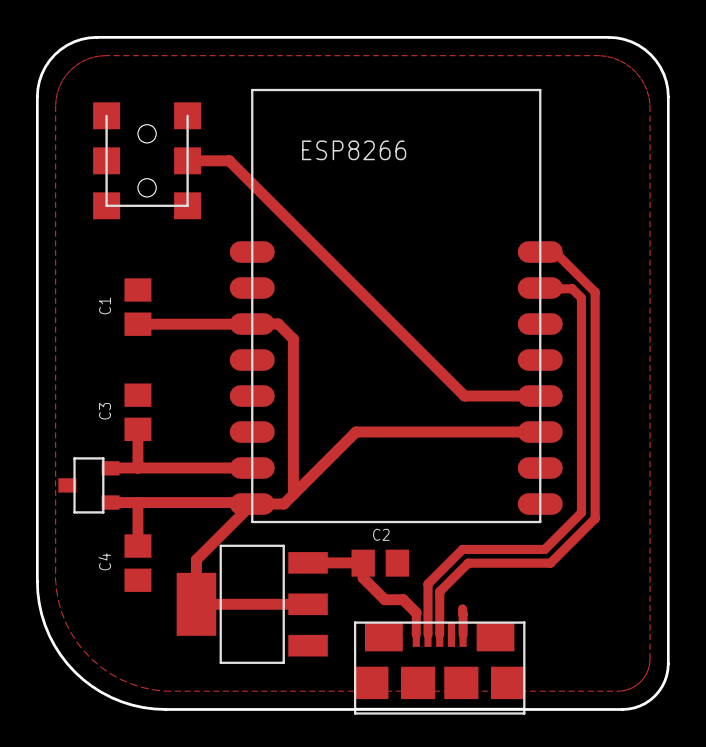
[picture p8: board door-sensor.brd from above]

Board: 2 copper layers, 35.1 x 37.3 mm, 9 parts (0 on the bottom side), 7 nets.

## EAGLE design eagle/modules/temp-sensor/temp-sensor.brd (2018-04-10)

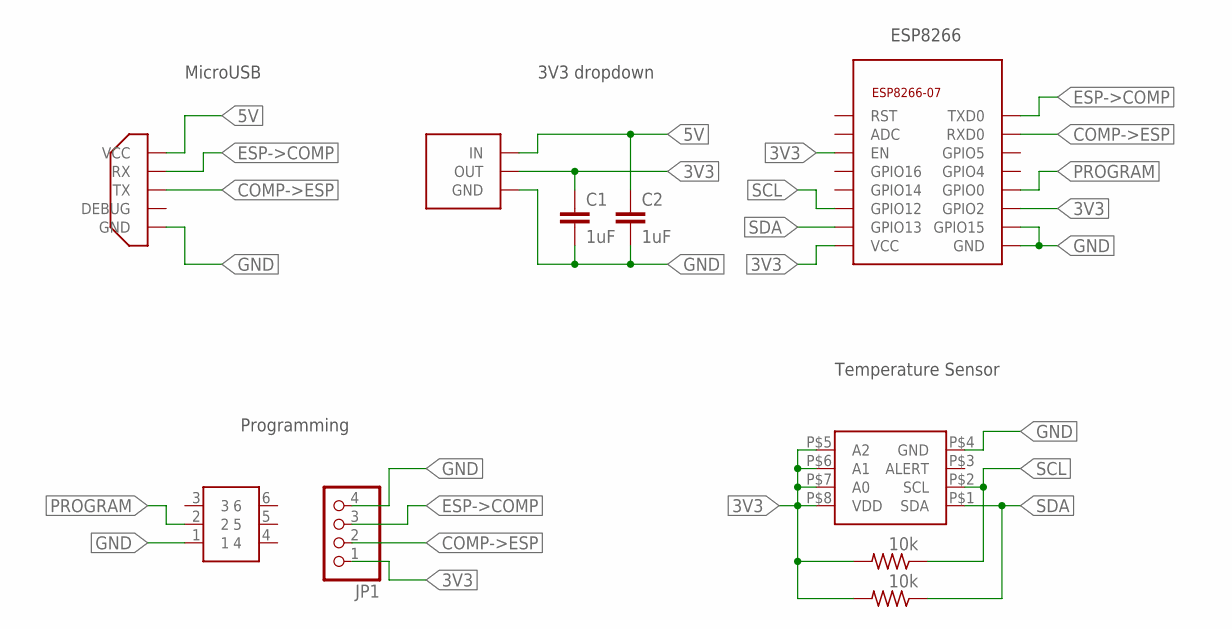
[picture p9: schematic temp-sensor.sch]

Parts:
C1, C2: 1uF; C0805
JP1: PINHD-1X4; 1X04
R1, R2: 10k; M0805
U$1: MCP9808; MSOP-8
U$2: ESP8266-12E-SMD
U$3: MICROUSB609-4613-1-ND; MICROUSB
U$4: AZ1117E; SOT-223
U$5: AYZ0202AGRL

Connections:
3V3: C1.1, JP1.1, R1.2, R2.2, U$1.P$5 (A2), U$1.P$6 (A1), U$1.P$7 (A0), U$1.P$8 (VDD), U$2.EN, U$2.GPIO2, U$2.VCC, U$4.P$1 (OUT), U$4.P$2 (OUT)
5V: C2.1, U$3.VCC, U$4.P$4 (IN)
COMP->ESP: JP1.2, U$2.RXD0, U$3.TX
ESP->COMP: JP1.3, U$2.TXD0, U$3.RX
GND: C1.2, C2.2, JP1.4, U$1.P$4 (GND), U$2.GND, U$2.GPIO15, U$3.GND, U$4.P$3 (GND), U$5.1
PROGRAM: U$2.GPIO0, U$5.2
SCL: R2.1, U$1.P$2 (SCL), U$2.GPIO12
SDA: R1.1, U$1.P$1 (SDA), U$2.GPIO13

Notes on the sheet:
Temperature Sensor
3V3 dropdown
ESP8266
MicroUSB
Programming

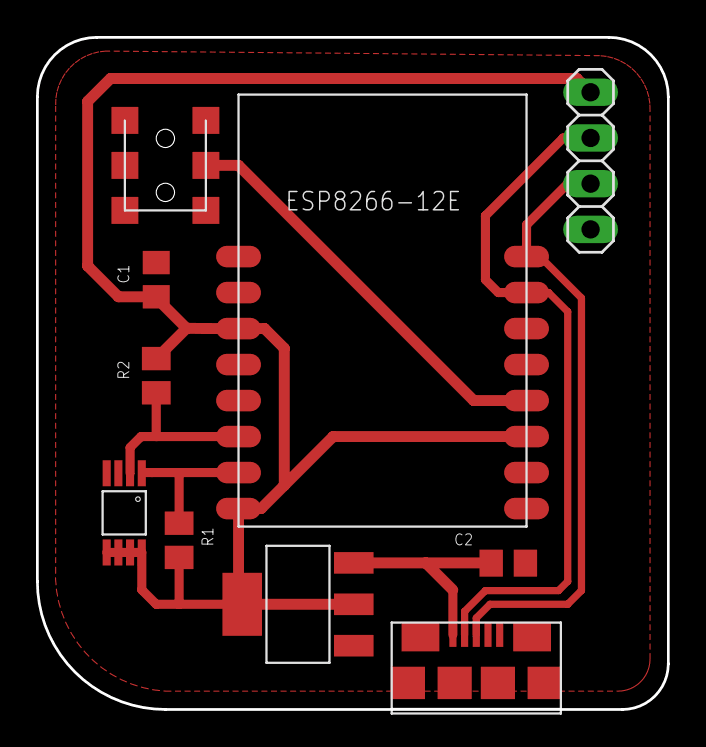
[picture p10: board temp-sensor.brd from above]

Board: 2 copper layers, 35.1 x 37.3 mm, 10 parts (0 on the bottom side), 8 nets.

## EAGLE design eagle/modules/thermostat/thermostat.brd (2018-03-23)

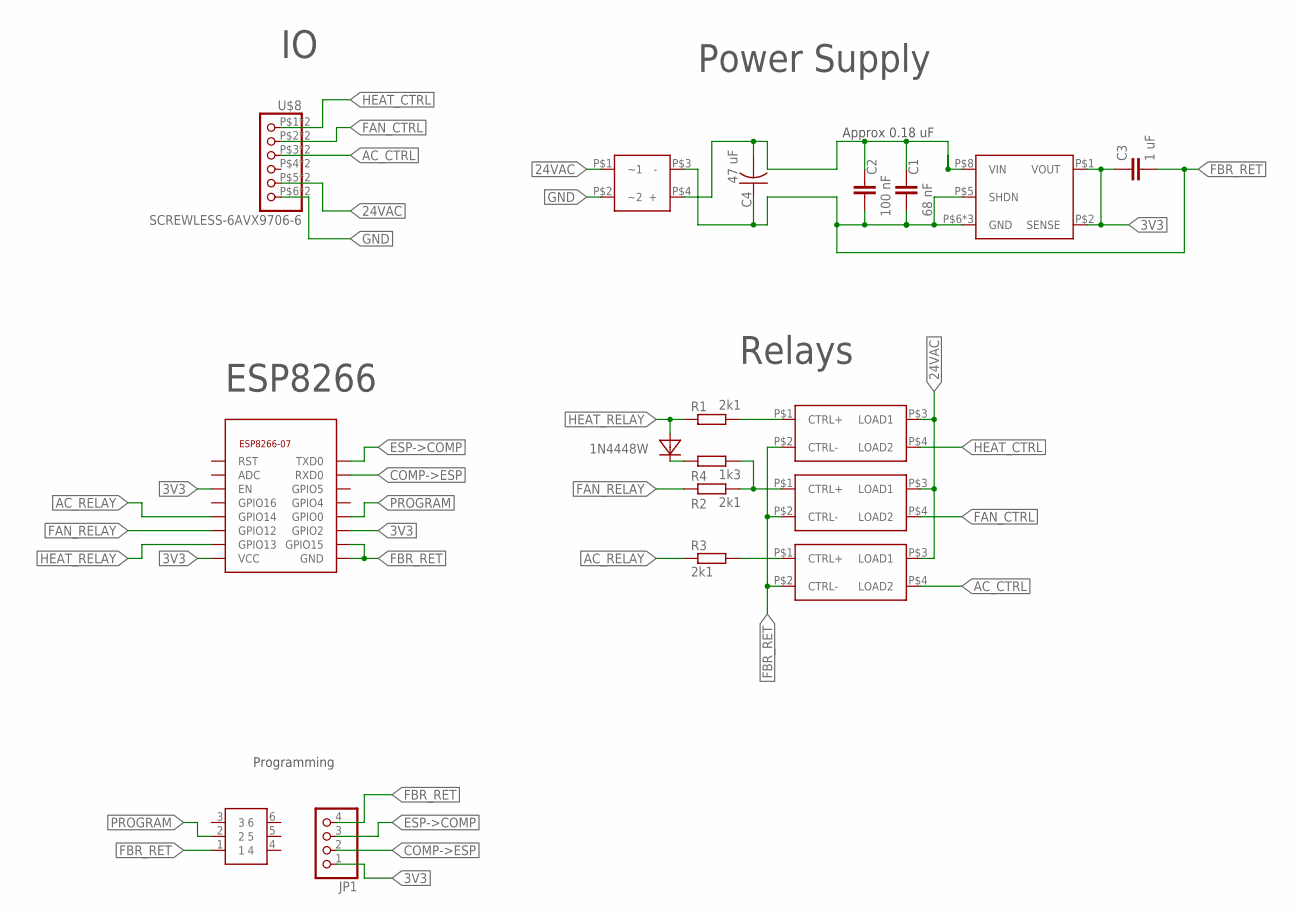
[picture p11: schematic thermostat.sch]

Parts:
C1: 68 nF; C0805
C2: 100 nF; C0805
C3: 1 uF; C0805
C4: 47 uF; UWT_GS
JP1: PINHD-1X4; 1X04
R1, R2, R3: 2k1; M0805
R4: 1k3; M0805
U$1, U$2, U$3: CPC1017N
U$4: ESP8266-12E-SMD
U$5: DS9068SOP-8; SOP-8
U$6: 1N4448W; SOD123
U$7: MB4S; TO-269AA
U$8: SCREWLESS-6AVX9706-6; AVX9706-6
U$9: AYZ0202AGRL

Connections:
3V3: C3.1, JP1.1, U$4.EN, U$4.GPIO2, U$4.VCC, U$5.P$1 (VOUT), U$5.P$2 (SENSE)
24VAC: U$1.P$3 (LOAD1), U$2.P$3 (LOAD1), U$3.P$3 (LOAD1), U$7.P$1 (~1), U$8.P$5 (5), U$8.P$11 (5)
32V: C1.1, C2.1, C4.ANODE (2), U$5.P$8 (VIN), U$7.P$4 (+)
AC_CTRL: U$3.P$4 (LOAD2), U$8.P$3 (3), U$8.P$9 (3)
AC_RELAY: R3.1, U$4.GPIO14
COMP->ESP: JP1.2, U$4.RXD0
ESP->COMP: JP1.3, U$4.TXD0
FAN_CTRL: U$2.P$4 (LOAD2), U$8.P$2 (2), U$8.P$8 (2)
FAN_RELAY: R2.1, U$4.GPIO12
FBR_RET: C1.2, C2.2, C3.2, C4.CATHODE (1), JP1.4, U$1.P$2 (CTRL-), U$2.P$2 (CTRL-), U$3.P$2 (CTRL-), U$4.GND, U$4.GPIO15, U$5.P$5 (SHDN), U$5.P$6 (GND), U$5.P$7 (GND), U$5.P$9 (GND), U$7.P$3 (-), U$9.1
GND: U$7.P$2 (~2), U$8.P$6 (6), U$8.P$12 (6)
HEAT_CTRL: U$1.P$4 (LOAD2), U$8.P$1 (1), U$8.P$7 (1)
HEAT_RELAY: R1.1, U$4.GPIO13, U$6.A
unnamed: R1.2, U$1.P$1 (CTRL+)
unnamed: R2.2, R4.2, U$2.P$1 (CTRL+)
unnamed: R3.2, U$3.P$1 (CTRL+)
unnamed: R4.1, U$6.C
PROGRAM: U$4.GPIO0, U$9.2

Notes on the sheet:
Approx 0.18 uF
Relays
Power Supply
ESP8266
Programming

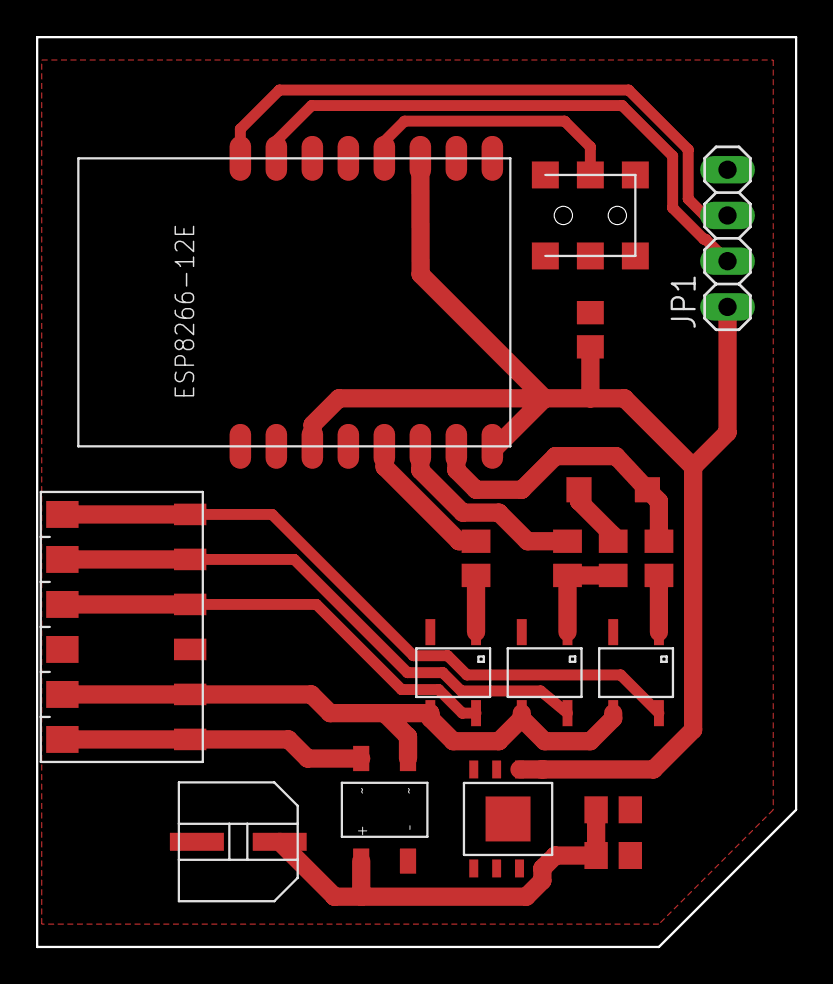
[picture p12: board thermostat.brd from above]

Board: 2 copper layers, 42.2 x 50.5 mm, 18 parts (0 on the bottom side), 18 nets.

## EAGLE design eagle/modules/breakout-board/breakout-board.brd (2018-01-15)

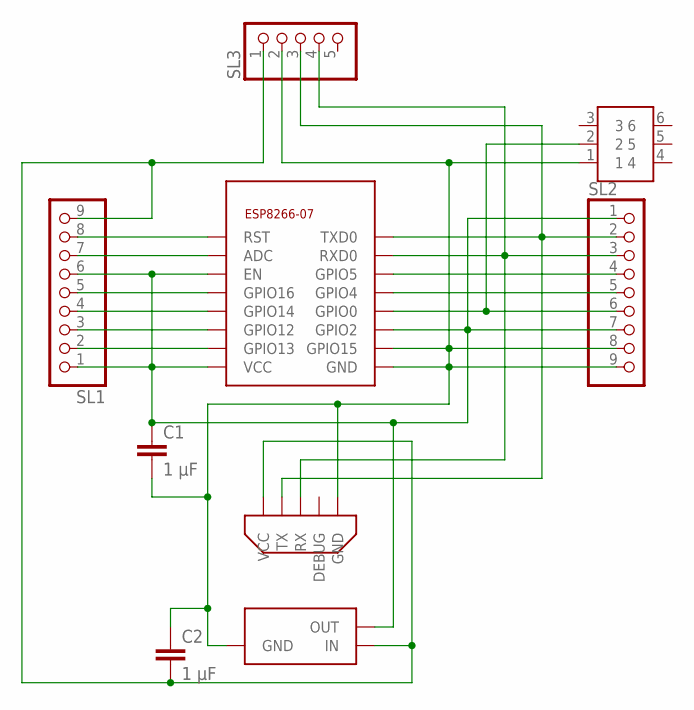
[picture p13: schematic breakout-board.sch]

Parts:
C1, C2: 1 µF; 0805
SL1, SL2: PINHD-1X9; 1X09
SL3: PINHD-1X5; 1X05
U$1: ESP8266-07HEADER; ESP8266-07-HEADER
U$2: MICROUSB609-4613-1-ND; MICROUSB
U$3: AYZ0202AGRL
U$4: AZ1117E; SOT-223

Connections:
unnamed: C1.1, SL1.1, SL1.6, SL2.1, SL2.7, U$1.EN, U$1.GPIO2, U$1.VCC, U$4.P$1 (OUT), U$4.P$2 (OUT)
unnamed: SL1.2, U$1.GPIO13
unnamed: SL1.3, U$1.GPIO12
unnamed: SL1.4, U$1.GPIO14
unnamed: SL1.5, U$1.GPIO16
unnamed: C2.2, SL1.9, SL3.1, U$2.VCC, U$4.P$4 (IN)
unnamed: SL1.7, U$1.ADC
unnamed: SL1.8, U$1.RST
unnamed: SL2.2, SL3.3, U$1.TXD0, U$2.TX
unnamed: SL2.3, SL3.4, U$1.RXD0, U$2.RX
unnamed: SL2.4, U$1.GPIO5
unnamed: SL2.5, U$1.GPIO4
unnamed: SL2.6, U$1.GPIO0, U$3.2
unnamed: C1.2, C2.1, SL2.8, SL2.9, SL3.2, U$1.GND, U$1.GPIO15, U$2.GND, U$3.1, U$4.P$3 (GND)

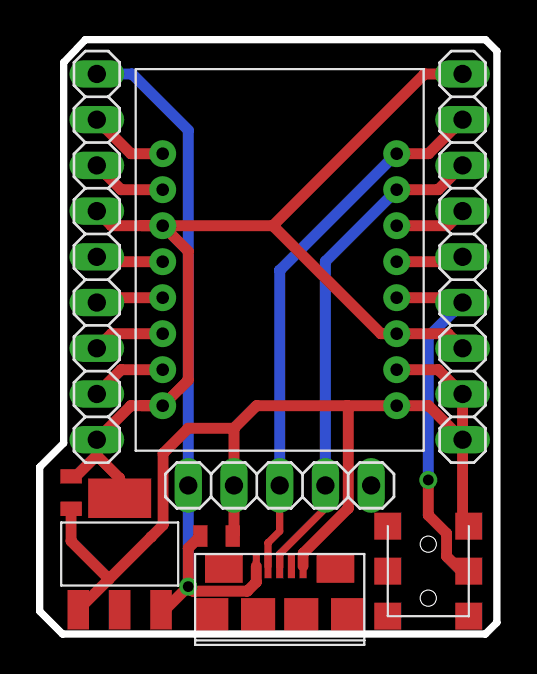
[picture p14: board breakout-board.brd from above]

Board: 2 copper layers, 25.4 x 33.0 mm, 9 parts (0 on the bottom side), 14 nets.

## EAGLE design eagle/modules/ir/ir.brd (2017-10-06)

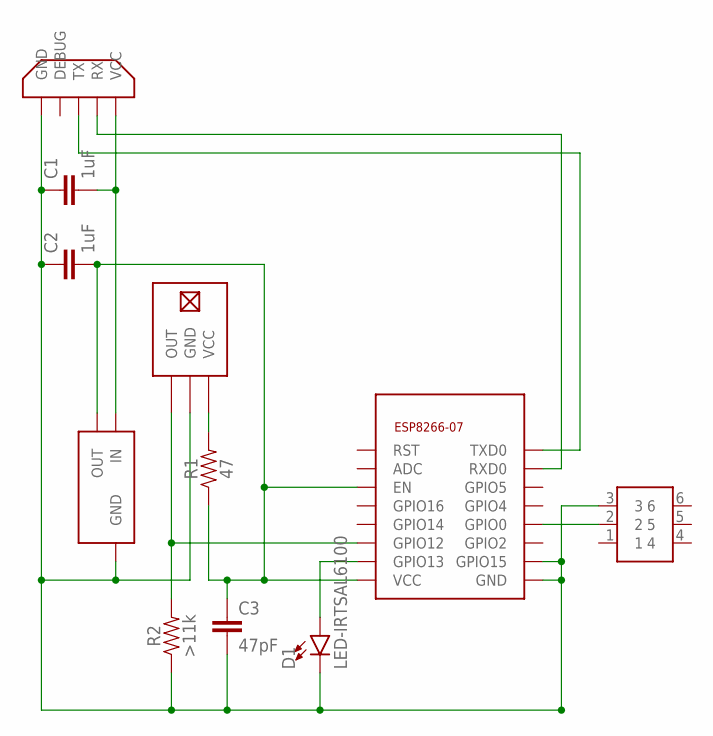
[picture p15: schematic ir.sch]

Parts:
C1, C2: 1uF; 0805
C3: 47pF; 0805
D1: LED-IRTSAL6100; LED_5MM
R1: 47; 0805
R2: >11k; 0805
U$1: AX-1838HSHORIZ; AX-1838HS-HORIZ
U$2: ESP8266-07SMD; ESP8266-07
U$3: AYZ0202AGRL
U$4: MICROUSB609-4613-1-ND; MICROUSB
U$5: AZ1117E; SOT-223

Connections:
unnamed: C1.2, U$4.VCC, U$5.P$4 (IN)
unnamed: C1.1, C2.1, C3.2, D1.K (C), R2.1, U$1.GND, U$2.GND, U$2.GPIO15, U$3.3, U$4.GND, U$5.P$3 (GND)
unnamed: R2.2, U$1.OUT, U$2.GPIO12
unnamed: U$2.GPIO0, U$3.2
unnamed: C2.2, C3.1, R1.1, U$2.EN, U$2.VCC, U$5.P$1 (OUT), U$5.P$2 (OUT)
unnamed: U$2.RXD0, U$4.RX
unnamed: U$2.TXD0, U$4.TX
unnamed: D1.A, U$2.GPIO13
unnamed: R1.2, U$1.VCC

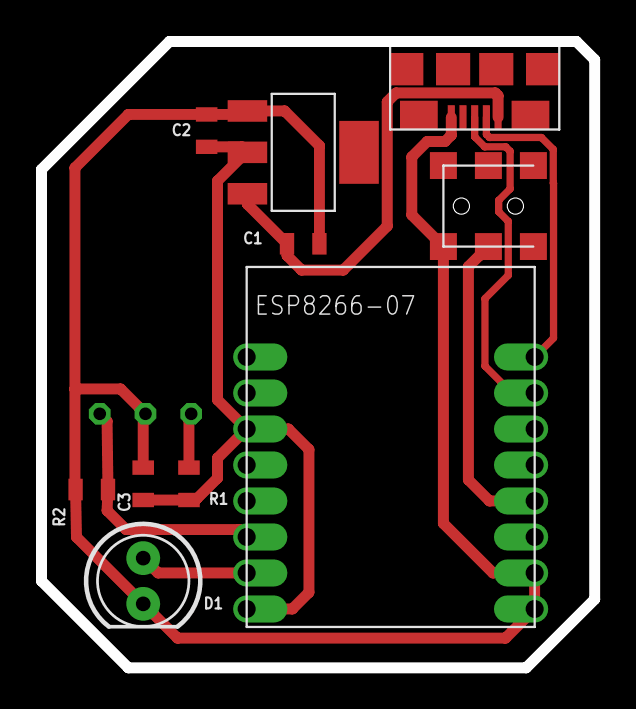
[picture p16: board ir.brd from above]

Board: 2 copper layers, 30.7 x 34.8 mm, 11 parts (0 on the bottom side), 9 nets.

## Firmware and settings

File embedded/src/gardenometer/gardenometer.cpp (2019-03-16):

#include <Arduino.h>

#include "Adafruit_TSL2591.h"
#include "Adafruit_MCP9808.h"
#include "idiotic_module.hpp"

#define SERIAL_BAUD 115200

const char *kServerHost = "192.168.1.182";
const int kServerPort = 5000;

IdioticModule module("Gardenometer");
Adafruit_MCP9808 tempSensor;
Adafruit_TSL2591 lightSensor(2591);


void setup() {
    Serial.begin(SERIAL_BAUD);

    module.connectWiFi();
    module.beginSocket(kServerHost, kServerPort);

    tempSensor.begin(13, 12, 0x18);

    if (!lightSensor.begin()) {
        Serial.println("Light sensor not found");
        while (1);
    }

    sensor_t sensor;
    lightSensor.getSensor(&sensor);
    Serial.println(F("------------------------------------"));
    Serial.print(F("Sensor:       "));
    Serial.println(sensor.name);
    Serial.print(F("Driver Ver:   "));
    Serial.println(sensor.version);
    Serial.print(F("Unique ID:    "));
    Serial.println(sensor.sensor_id);
    Serial.print(F("Max Value:    "));
    Serial.print(sensor.max_value);
    Serial.println(F(" lux"));
    Serial.print(F("Min Value:    "));
    Serial.print(sensor.min_value);
    Serial.println(F(" lux"));
    Serial.print(F("Resolution:   "));
    Serial.print(sensor.resolution, 4);
    Serial.println(F(" lux"));
    Serial.println(F("------------------------------------"));
    Serial.println(F(""));

    // Set the gain to low for outside use
    lightSensor.setGain(TSL2591_GAIN_LOW);

    module.funcs["temp"] = IdioticModule::function_map{
            .get = [&] {
                return tempSensor.readTempC();
            }
    };
    module.funcs["lux"] = IdioticModule::function_map{
            .get = [&] {
                uint16_t bothChannels = lightSensor.getLuminosity(TSL2591_VISIBLE);
                uint16_t infrared = lightSensor.getLuminosity(TSL2591_INFRARED);

                return lightSensor.calculateLux(bothChannels, infrared);
            }
    };
}

void loop() {
    module.dataLoop();

    delay(2000);
}

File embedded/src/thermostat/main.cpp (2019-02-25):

#include "idiotic_module.hpp"
#include "thermostat.hpp"

// Debug Serial
#define SERIAL_BAUD 115200

// Idiotic
#define SERVER_HOST "192.168.1.108"
#define SERVER_PORT 5000
IdioticModule module("Thermostat");

// Thermostat
Thermostat thermostat(12, 14, 13);

// Forward declarations
void setThermostatMode(const char *);
const char *getThermostatMode();

// Setup function
void setup() {

    Serial.begin(SERIAL_BAUD);
    module.connectWiFi();

    module.beginSocket(SERVER_HOST, SERVER_PORT);

    // Functions use to set or get thermostat mode
    module.funcs["mode"] = IdioticModule::function_map {
            .get = &getThermostatMode,
            .set = &setThermostatMode
    };
}

// Looping function
void loop() {
    //  Iterate over all functions and send result of .get functions to server
    module.dataLoop();
    delay(2000);
}

// Change which mode thermostat is set to
void setThermostatMode(const char *mode) {

    if (!strcasecmp(mode, "ac"  )) thermostat.setMode(Thermostat::kAC);
    if (!strcasecmp(mode, "fan" )) thermostat.setMode(Thermostat::kFan);
    if (!strcasecmp(mode, "heat")) thermostat.setMode(Thermostat::kHeat);
    if (!strcasecmp(mode, "none")) thermostat.setMode(Thermostat::kNone);

}

// Retrieve current thermostat mode
const char *getThermostatMode() {

    switch (thermostat.getMode()) {
        case Thermostat::kAC  : return "ac"  ;
        case Thermostat::kFan : return "fan" ;
        case Thermostat::kHeat: return "heat";
        case Thermostat::kNone: return "none";
    }
}

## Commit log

2017-03-23 Added LP2980-N (SMD 3.3V Regulator)
2017-03-25 Started aquiring files for SMD switchover
2017-03-26 Renamed directories to be more reflective of contents
    [Headers.brd, Headers.sch, MicroUSB.brd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]
2017-07-24 Added board and schematic backups to .gitignore
2017-07-24 Created Purchase directory to track money spent on project
2017-07-24 Directory for Gerber files
2017-07-24 Updated MicroUSB board
    [MicroUSB_SMD.brd, MicroUSB_SMD.sch]
2017-07-24 Created a breakout board for debugging purposes
    [BreakoutBoardReg.brd, BreakoutBoardReg.sch]
2017-07-30 Rudimentary web server and conditional actions using door sensor
2017-07-30 Renamed door sensor http directory/file to be more descriptive
2017-09-01 Directory structure overhaul
    [Headers.brd, Headers.sch, MicroUSB.brd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]
2017-09-05 Fixed pinout of female microusb. Previosly GND/ID was connected to TX instead of NC.
    Fixed width of SMD esp8266. Now using inside holes instead of outside
    ones.
    [breakout-board.brd, breakout-board.sch]
2017-09-20 IR signal recorder
    [ir-duplicator.sch]
2017-09-21 Added comments to outline what each ignore is for. Added gerber zips
2017-09-21 Resized drill holes in header footprints. Also changed to new library for the headers Issue #1
    [breakout-board.brd, breakout-board.sch]
2017-09-25 Removed glue from export
2017-09-25 Schematic now uses correct tx and rx pins on USB
    [ir-duplicator.sch]
2017-09-25 Initial board for IR duplication
    [ir-duplicator.brd]
2017-09-25 Gerber files for IR duplicator board
2017-09-25 Switched USB rx and tx pins in schematic
2017-10-06 IR board
    [ir.brd, ir.sch]
2017-10-26 Simple Flask server. Supports messages from door sensor as well as future messages from API.ai. (Still needs https certs)
2017-11-10 Now uses domain and lights an LED
2017-11-22 Initial attempt at creating shape of devices
2017-11-29 Added functionality to hue devices
    The majority of the addition is for group support
    Resolves #7
2018-01-15 Some old eagle changes. I don't remember what they were for and diffing is impractical
    [breakout-board.brd]
2018-01-15 Start of routine functionality Created framework for IotRoutine
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2018-01-15 Framework for IotConditional callability (is that a word?)
2018-01-25 Temperature sensor module
    [temp-sensor.brd, temp-sensor.sch]
2018-01-25 Some documentation for temperature sensor
2018-01-25 README for temperature sensor
2018-01-25 Units for temperature reporting
2018-01-25 Symlink to eagle directory for temp-sensor
2018-01-25 Reduced page size
    [temp-sensor.brd]
2018-02-01 Send requests to webserver to change attributes of IotDevices. Currently hardcoded to HueDevices
2018-02-04 Initial ESP8266 program to read temperature from MCP9808
2018-02-05 Created library directory and added start of common ESP8266_IoT library
    Currently allows sending single attribute values
2018-02-05 Now sends temperature to server. Uses ESP8266_Iot library
2018-02-07 Added pullup resistors to PCB and made board part labels for RC components proper
    [temp-sensor.brd, temp-sensor.sch]
2018-02-08 Switched to platformio build system. Goodbye Arduino IDE!
2018-02-08 Switched to ArduinoJson for creating Json structures. temp-sensor now sends correctly formatted Json
2018-02-08 Added orientation idicator to MCP-9808's package
    [temp-sensor.brd, temp-sensor.sch]
2018-02-08 Moved label for one of resitors to avoid confusion
    [temp-sensor.brd]
2018-02-08 Removed board outline from Top and Bottom outputs. Added Top-only export
2018-02-08 Removed second board outline
    [temp-sensor.brd]
2018-02-11 Renamed arduino directory to embedded as old name was a little misleading
2018-02-12 Added RT9068 3.3V regulator
2018-02-12 Split library up into multiple libraries based on device type
    [temp-sensor.brd, temp-sensor.sch]
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2018-02-14 Connected traces that need internal connections
2018-02-14 Thermostat module
    [thermostat.brd, thermostat.sch]
2018-02-18 Devices are now queried for their actions and attributes Actions are now functions wrapped by class instances instead of functions (similar to Attributes)
2018-02-21 Added __init__.py file for easier device importing
2018-02-22 Added ESP8266-12E and ESP8266-12E-SMD Renamed device to ESP8266
2018-02-22 Added way of programming boards - header and GPIO0 switch
    [temp-sensor.brd, temp-sensor.sch, thermostat.brd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]
2018-02-22 Pins were connected to incorrect pad and device was polarized backward. This has been resolved
2018-02-22 Changed drill size to mil
2018-02-22 Only one active device at a time. Why store state of all three?
2018-03-02 Attempt at using Websockets (currently does not work)
    [main.cpp, thermostat.cpp]
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2018-03-13 Routine configuration can now happen before devices say hello
2018-03-15 Devices, events, and routines can be loaded from json before server init
2018-03-23 Fixed package for DS9068 regulator
    [thermostat.brd, thermostat.sch]
2018-03-23 Added thermostat to device __init__ file
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2018-04-10 Added labels to schematics
    [MicroUSB_SMD.brd, MicroUSB_SMD.sch, breakout-board.sch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]
2018-04-10 Added images of boards and schematics
2018-04-10 Switced SDA and SCL pins for temp sensor to match board. Removed temp2
2018-04-10 Gerber files for temp sensor and thermostat
    [gerber_job.gbrjob]
2018-04-10 Fixed VCC pin on MCP9808. MCP adr on TS to 0x1F
    [temp-sensor.brd, temp-sensor.sch]
2018-04-10 door-sensor board V2 using new skills
    [door-sensor.brd, door-sensor.sch]
2018-04-16 Removed the model specific '-12E' text on ESP8266 schematic and package
2018-04-16 Removed old door-sensor boards and schematics
    [Headers.brd, Headers.sch, MicroUSB.brd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]
2018-04-16 Renamed idiotic_devices/ to device_drivers/
2018-04-19 README device driver template improvements
2018-04-19 Moved new device driver info to README in device_drivers/
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2018-04-20 Added temperature sensor and hue light mentions to root readme
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2019-02-25 Switch to using WiFiManager instead of hardcoding SSID/Password
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2019-03-16 Added a new Gardenometer device
    - Added the firmware for the new device
    - Added a new device driver

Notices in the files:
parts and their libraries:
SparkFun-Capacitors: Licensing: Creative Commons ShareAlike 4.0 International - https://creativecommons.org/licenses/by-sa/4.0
